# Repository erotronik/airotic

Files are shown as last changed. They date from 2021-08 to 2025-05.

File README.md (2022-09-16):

# Airotic

The next generation of bubbler bottles, with RGB lighting and bluetooth.

## Features

* Borosilicate glass bottle, easy to clean, harder to break
* Customizable RGB lighting which works with or without liquid
* Breath sensor detects each breath and causes the colours to change and fade
* Bluetooth server allows bottles to be customised from your phone
* Proximity sensing lets bottles change colours and modes as they get close to their friends
* Bluetooth client allows other hardware to interact and "do things" based on breaths
* Air input is through vents not a pipe, for aesthetics and safety
* Low cost compared to commercial bottles
* Uses easily sourced parts including bottle, pressure sensor module, Bluetooth Arduino board
* Powered by small USB portable power pack, will run for a day even on the smallest packs
* Can connect to Coyote DG-Labs e-stim box
* Other features and modes to be announced and released
* Open Source software and hardware design

## Background

After discussing how expensive and poorly designed clear bubbler bottles were over a take-away meal, [@toydolly](https://github.com/toydolly) and [@jlatex](https://github.com/jlatex) figured that we could design and make something even better.

Of course it would need little LED lights to make the liquid glow. And bluetooth.  And soon what was a simple "bottle, 3d printed bottle cap, and tube", turned into an Arduino powered, bluetooth, breath detecting, co-operative and interactive project. [Everything is better with Bluetooth](https://youtu.be/0KXoBcQER_0?t=102). 

We really didn't want to make and sell them. So why not build your own? Please do tag and show us if you build one. If you make any improvements to the hardware or software we'd love to see them too, drop an issue or PR here.

## Safety

This bubbler bottle is designed for your own personal use in a situation where you have the ability to disconnect your mask. It is not designed to restrict or block any ability to breathe. The bottle also works just fine without any liquid and will still light up and detect breathing. If you plan to use them at an event please check with an event organiser first.

## Battery Safety

We have designed the bubbler bottle to use an external USB Powerbank. This is deliberate and we did not want to use a LIPO battery. We have personally witnessed several LIPO failures over the years, some while charging, but not always. The last thing you want is your LIPO battery to explode or start venting lithium gasses into your breathing path. 

## Build your own

To make your own bottle you need to buy a few things, 3D print a few things, solder a few things, and use a PC to upload the program.

* [mechanical construction detail and 3D files](mechanical/)
* [electronics construction details](electronics/)
* [programming details](arduino/)
* [user guide](userguide/)

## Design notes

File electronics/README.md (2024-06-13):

# Bubbler Bottle electronics and programming

## Parts list

|Item|UK Seller|USA Seller|
|--|--|--|
| Adafruit Itsy Bitsy NRF52480 Express |[Pimoroni](https://shop.pimoroni.com/products/adafruit-itsybitsy-nrf52840-express-bluetooth-le)| [Adafruit](https://www.adafruit.com/product/4481) |
| BMP280 Barometric pressure sensor |[various ebay sellers](https://www.ebay.co.uk/itm/283518687928)|[various ebay sellers](https://www.ebay.com/itm/133104662930)|
| 2 pairs of micro 3 pin JST 1.25 connectors (or any small 3 pin connectors or just hard wire instead) |[various ebay sellers](https://www.ebay.co.uk/itm/301857866521)|[Adafruit](https://www.adafruit.com/product/4721)|
| Two WS2812b (neopixels) on small round PCB|[various ebay sellers](https://www.ebay.co.uk/itm/203167394144)|[Adafruit](https://www.adafruit.com/product/1612)
| A tiny bit of double sided foam tape (or hotglue)||[Adafruit](https://www.adafruit.com/product/5019)|
| one M2.5 5mm screw|any hardware store or ebay|

Note that it is now possible to use an ESP32 instead of the Adafruit Itsy Bitsy; see this [separate readme](ESP32.md).

## Construction

### Step 1

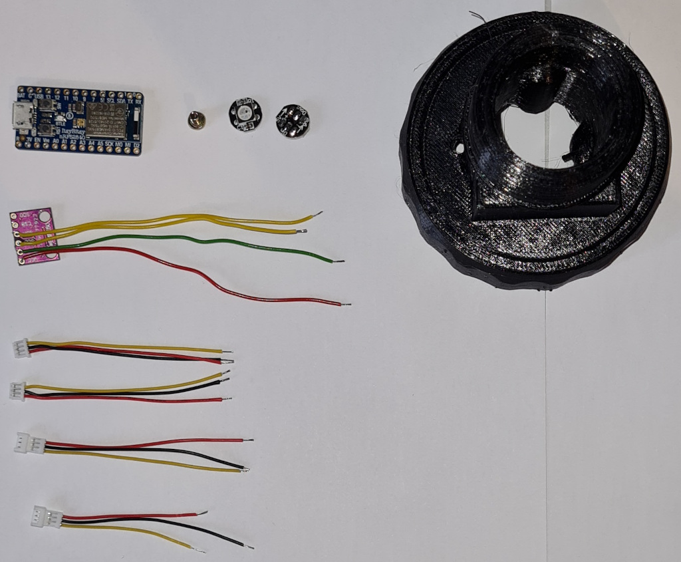
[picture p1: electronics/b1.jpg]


* Shorten 2 male and 1 female JST leads to around 60mm on all 3 connectors, strip, and tin
* Shorten the other female JST lead, black to around 55mm, red and yellow to around 40mm, strip
* Add thin wires to the BMP280 module so the wires come out on the blank side not the component side.  Trim the solder joints so they are not too prominent.  Solder wires about 100mm long to +v and gnd, and wires about 90mm long to SDA and SCL
* Tin the connections on the LED modules to aid assembly.  Do a test fit and make sure they fit in the cap.

### Step 2

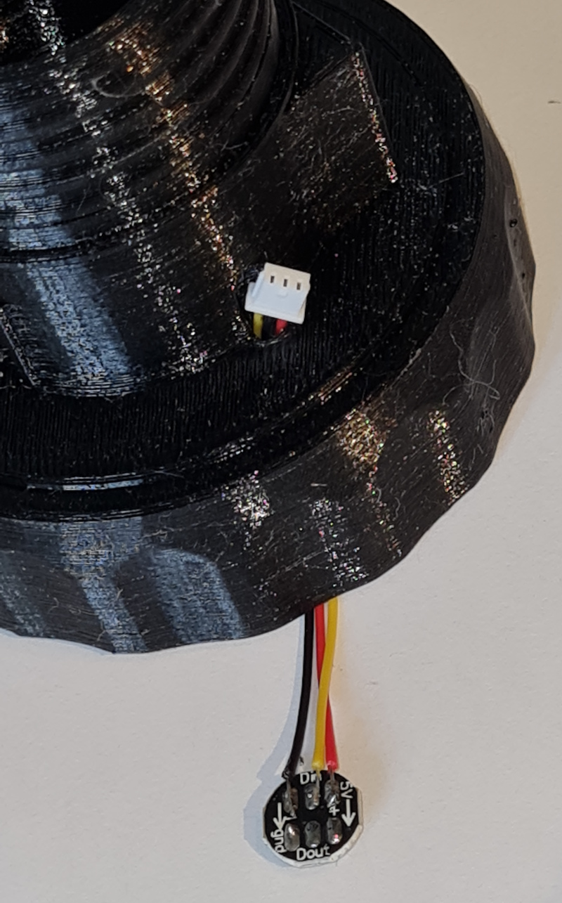
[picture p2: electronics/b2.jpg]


* Feed a male JST through the left hole (left when the flat mounting panel facing you). Solder it to one of the neopixels. Yellow is to DIN, Red is +5V, Black to gnd.  There are no connections to the other 3 pins.

### Step 3

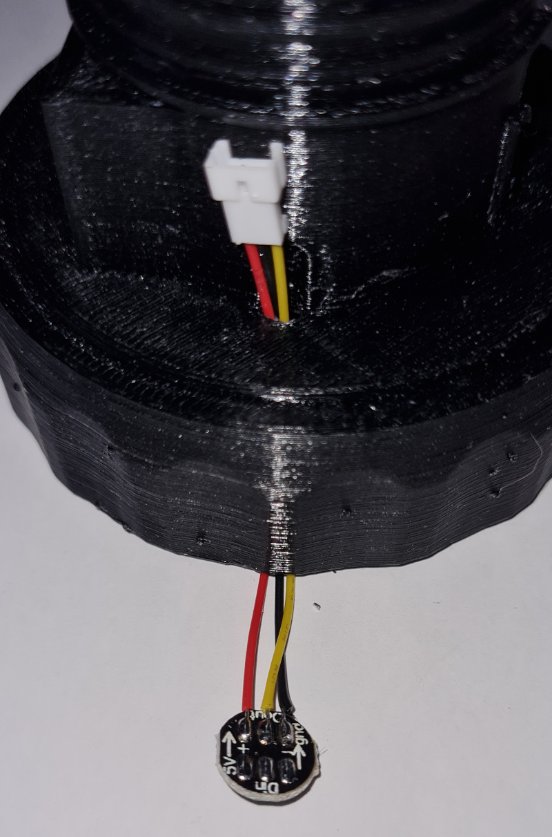
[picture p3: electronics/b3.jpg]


* Feed the 60mm-lead female JST through the right hole. Solder it to the other neopixel. Yellow is DOUT, Red is +5v, black to gnd.

### Step 4

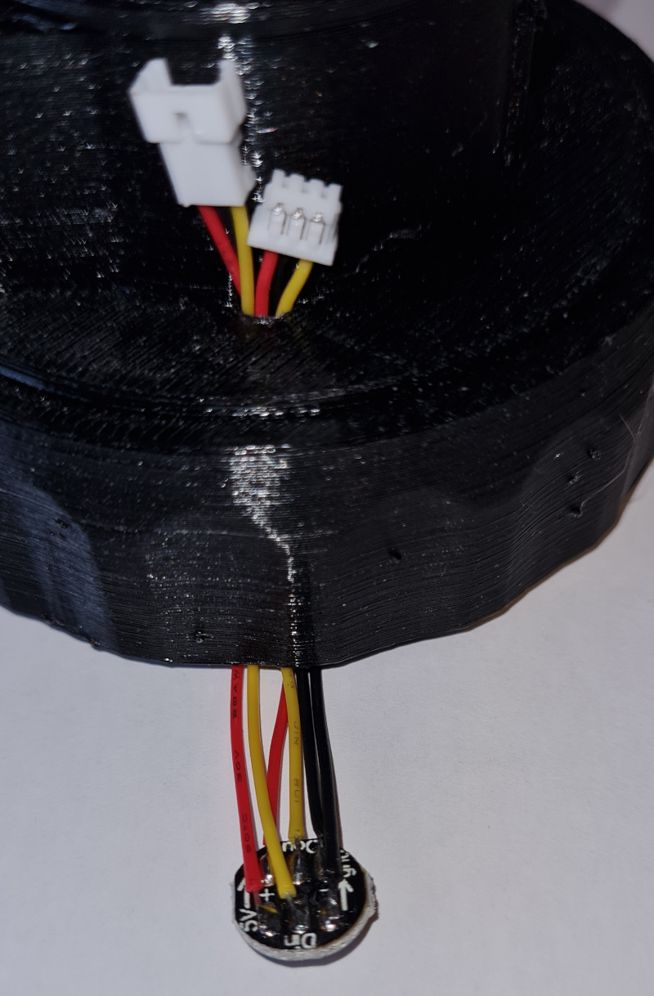
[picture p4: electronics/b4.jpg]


* Feed the remaining male JST lead through the same hole and solder it to the other side of the neopixel. Yellow is DIN, Red is +5v, black to gnd. Solder it so the leads all exit from the same side if possible.  Check your connections carefully make sure DIN and DOUT are not touching.

### Step 5

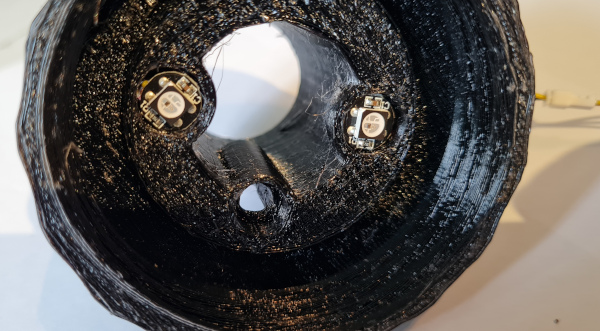
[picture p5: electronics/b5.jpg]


* Carefully push the LEDs back up into the holes for them and bend the wires so they fit as flat as possible. You could install the LED covers at this point to keep them in place.

### Step 6

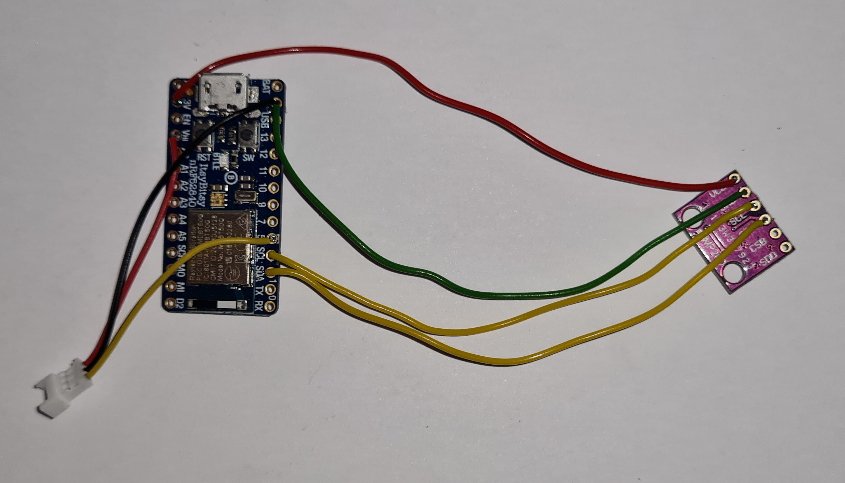
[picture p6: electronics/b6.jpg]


* Solder the remaining JST female and BCM280 board to the Itsy Bitsy.  Start with the GND wire as you need to fit two wires into the same hole.  With thin enough wires this should be fairly easy. Then the JST female red wire goes to the VHI pin, and the JST socket yellow wire goes to the "5!" pin.

* Solder the other wires from the BCM280 board. The red leads goes to 3V, SCL to SCL, and finally SDA to SDA.

### Step 7

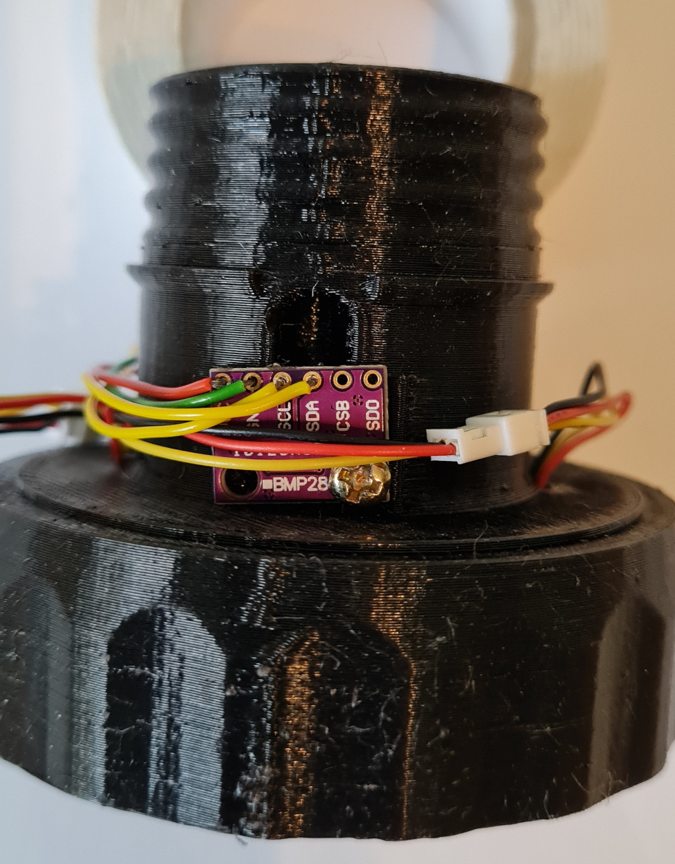
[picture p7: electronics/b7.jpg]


* You can mount the BMP280 board over the air hole using the M2.5 screw. Ensure the component side of the board is against the hole with the leads at the top as shown.  Important: make sure the sensor (the 2mm square silver part) is facing inwards, against the hole.
* Connect all the JST cables and bend/tuck them out of the way.

### Step 8

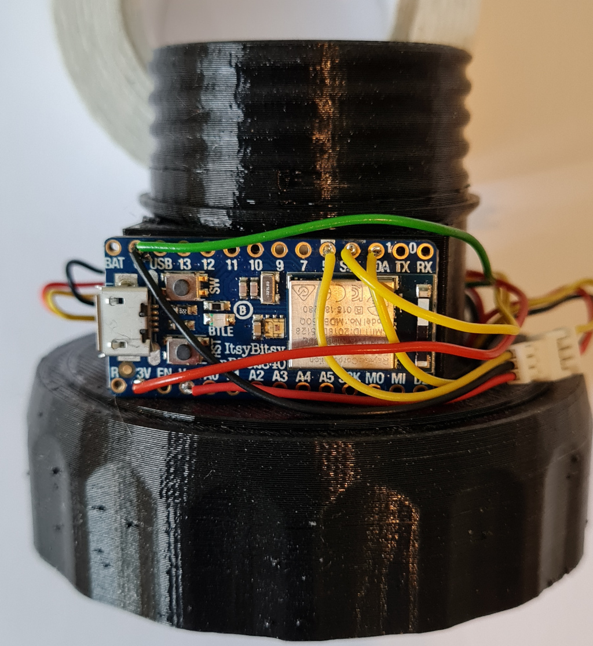
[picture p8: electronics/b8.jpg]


* Secure the Itsy Bitsy board with a bit of double sided foam tape (or hotglue)

That's it, now you just need to program and test.

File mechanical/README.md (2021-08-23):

# Printing and assembling the bottle
## Parts list:
* The STL files for the cap, cover, spigot and LED covers
* A [RYACO 800ml wide mouth bottle](https://www.amazon.co.uk/dp/B088B7RL98/ref=cm_sw_r_tw_dp_RTAABATTSC8DW0E9HZ2Y)
* The seal from the lid of the RYACO bottle
* A short length of 6mm tubing
* Some superglue or similar adhesive

## Construction
### Step 1
* Slice the STL files to suit your 3D printer
* We sliced in Cura at a 0.2mm layer height with supports and 20% infill
### Step 2
* Print your parts 
* We printed in both PLA and PETG for the cap, cover and spigots
* You will need to use transparent filament for the LED caps
### Step 3
* Remove support materials (if you needed supports on the cap, be gentle around the vents)
* Check that the cap fits the bottle properly before proceeding
### Step 4
* On the underside of the cap, superglue the spigot into the hole and leave to set
### Step 5
* Sand, paint or finish to your own taste
* We suggest not altering the area of the cap where the electronics will go to avoid changing the fit
* You can remove the logo on the bottle with a sharp blade by carefully scraping the letters off.
### Step 6
* Remove the seal from the RYACO bottle lid and insert it into the channel on the cap's underside
### Step 7
* Proceed to assembling the electronics before attaching the tube to the spigot for ease of handling.

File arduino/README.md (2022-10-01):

# Bubbler Bottle programming

Note - there is a [separate Readme if you use an ESP32](ESP32.md).

## Programming setup

* Install the arduino tool and board support. [Use this Adafruit guide](https://learn.adafruit.com/adafruit-itsybitsy-nrf52840-express/arduino-support-setup)
* In the arduino tool goto "Tools" "Manage Libraries"
  * Search for "FastLED" and install it
  * Search for "BMP280" and install "Adafruit BMP280 Library"
  * Search for "spiflash" and install "Adafruit_SPIFlash"
  * Search for "NeoPixel" and install "Adafruit NeoPixel"

## Programming first step

* Select the board "ItsyBitsy nRF52840 Express"
* First you need to format the storage we use.  You should only ever need to do this once.  So open the examples "Adafruit SPIFlash" "SdFat_format", write it to the board, open the serial console, and select OK to flash.

## Programming

* Download the Bubbler code and upload it to the board.  On the first run the code will store some defaults and reboot, so it will take a bit longer

* On startup the code will cause both the LEDs to light up white, then shortly after they'll turn pink then fade to red. Blowing hard around the sensor hole will cause them to turn pink and fade back to red again.

Now you can connect to the board via bluetooth and set some defaults if you wish

## Troubleshooting

* On startup both LEDs should turn white briefly. If only one turns white check the connections between the LEDs.

* If the blowing over the sensor doesn't cause anything to happen, look at the serial console in the Arduino
application when starting up. It may be that the sensor isn't being detected. This could be because of a bad
sensor (out of the 6 we bought 1 was faulty) or the connections are bad (check SDA and SCL are the right way
around)

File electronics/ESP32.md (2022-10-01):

# Using an ESP32 for the Bubbler

Instead of the "Adafruit Itsy Bitsy NRF52480 Express", you also can use an ESP32, specifically an "Adafruit QT Py ESP32-C3" ([Adafruit (US)](https://www.adafruit.com/product/5405) / [Pimoroni (UK)](https://shop.pimoroni.com/products/adafruit-qt-py-esp32-c3-wifi-dev-board-with-stemma-qt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)).

Note - it is possible that you can also use other ESP32 boards with the same form factor. However, we only tested this specific board.

To use this board, use the [main construction manual](README.md) with the following changes:

To solder the JST and the BMP280 boards to the ESP32, start with the GND wire, as you need to fit two wires into the same hole. The JST female red wire goes to the "5V" pin, the jst socket yellow wire goes to the "A0" PIN.

Solder the other wires from the BCM280 board. VCC on the BMP280 goes to the "3V" pin, SDA goes to the "SDA" pin and SCL goes to the "SCL" pin.

Since the Adafruit QT Py has a Stemma QT port, you can also solder the BMP280 to a 4-pin JST-ST/Stemma QT cable, and plug that cable into the Qt Py. Suitable cables are available at [Adafruit (US)](https://www.adafruit.com/product/4399) / [Pimorino (UK)](https://shop.pimoroni.com/products/jst-sh-cable-qwiic-stemma-qt-compatible?variant=31910609813587). You will probably have to get a cable with two JST-SH ports, and cut it apart.

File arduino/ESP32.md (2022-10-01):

# ESP32 Bubbler Bottle programming

This is the programming guide if you choose to use an ESP32 instead of the (recommended) ItsyBitsy nRF52840 Express. For the ItsyBitsy, please [see the main readme](README.md).

## Programming setup

* Install the [Arduino IDE](https://www.arduino.cc/en/software) and [the Espressif ESP32 boards](https://espressif-docs.readthedocs-hosted.com/projects/arduino-esp32/en/latest/installing.html)
* In the Arduino IDE, go to "Tools"->"Manage Libraries"
* Search for, and install the following libraries:
	- FastLED
	- Adafruit NeoPixel
	- NimBLE-Arduino
	- Adafruit BMP280 Library

## Programming
* Select the board "Adafruit QT Py ESP32-C3"
* Download the Bubbler code and upload it to the board. On the first run the code will store some defaults and reboot, so it will take a bit longer.
* On startup the code will cause both the LEDs to light up white, then shortly after they'll turn pink then fade to red. Blowing hard around the sensor hole will cause them to turn pink and fade back to red again.

Now you can connect to the board via bluetooth and set some defaults if you wish

## Wifi Support

You can enable wifi support by changing the `ENABLE_BLE` and `ENABLE_WIFI` defined inside `bubbler.ino`.

Wifi support is quite rough at the moment; if you want to use it you should be familiar with Arduino programming and look at wifi.ino.

To use Wifi, you need to install the following additional libraries using the library manager:
* AsyncMQTT_Generic

You also have to manually install the following library that is not available via the library manager:
* https://github.com/me-no-dev/AsyncTCP

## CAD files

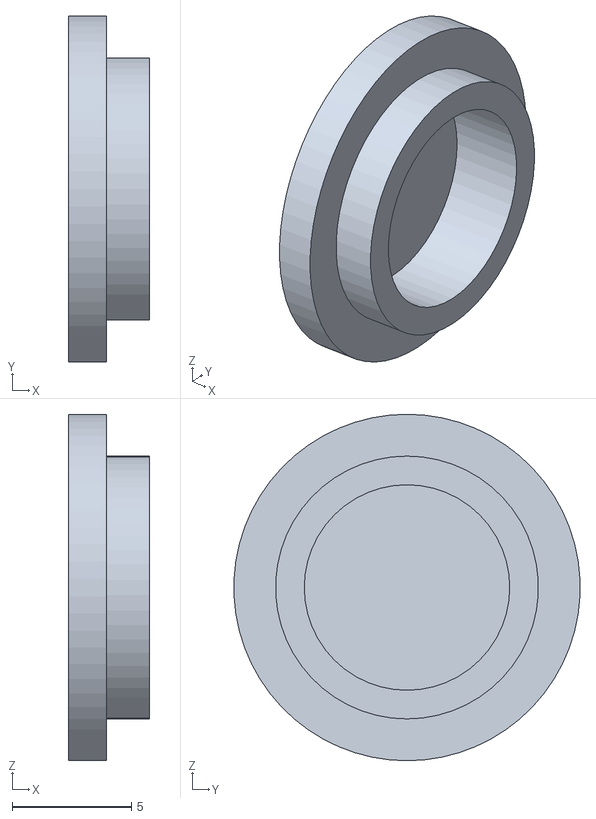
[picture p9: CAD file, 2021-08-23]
mechanical/2501-004 A.STL
3.40 x 14.5 x 14.5

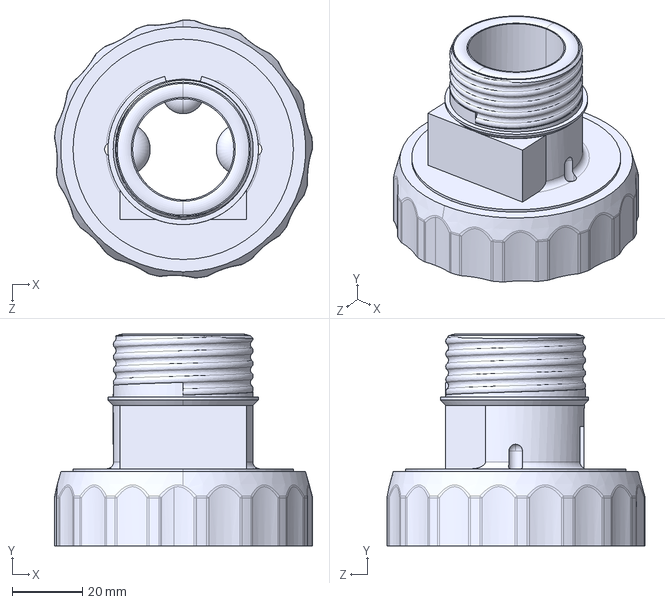
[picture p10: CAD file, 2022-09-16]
mechanical/STEP Files/2501-001.STEP
73.5 x 60.4 x 73.5 mm

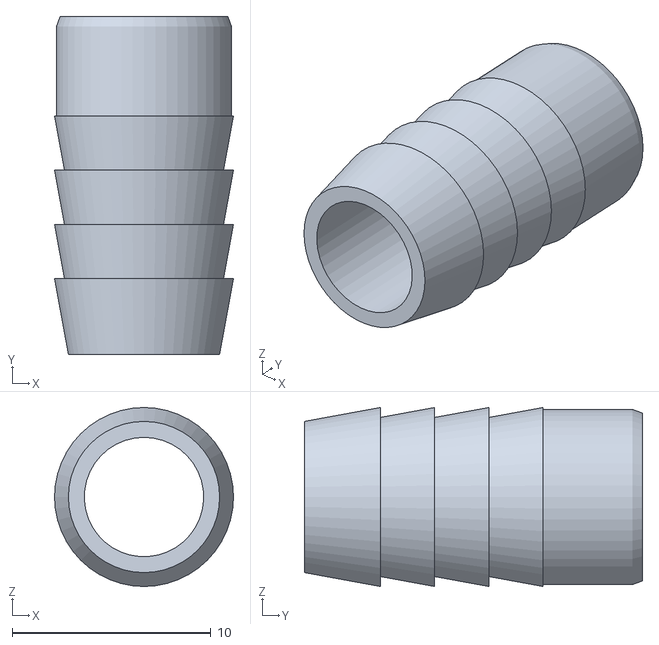
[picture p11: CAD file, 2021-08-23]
mechanical/2501-003 A.STL
9.00 x 17.0 x 9.00

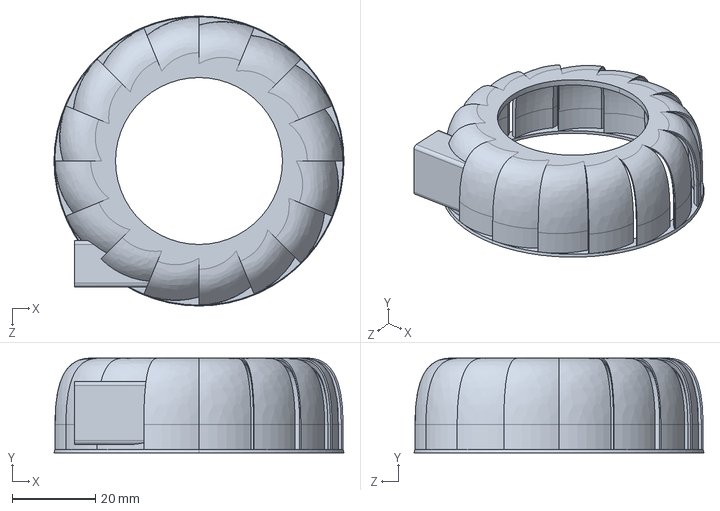
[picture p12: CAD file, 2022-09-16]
mechanical/STEP Files/2501-002.STEP
69.8 x 22.8 x 69.8 mm

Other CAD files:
mechanical/2501-001 A.STL
mechanical/2501-002 A.STL

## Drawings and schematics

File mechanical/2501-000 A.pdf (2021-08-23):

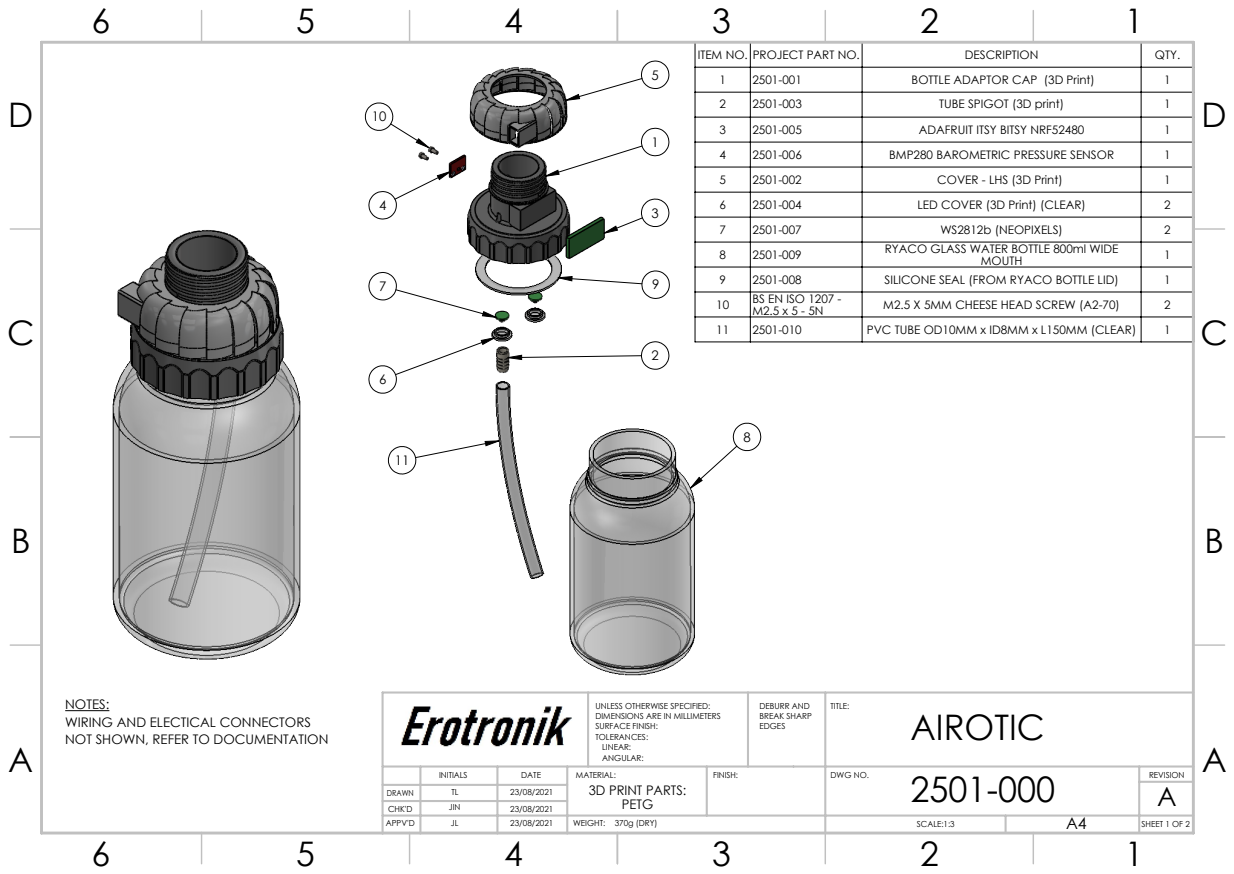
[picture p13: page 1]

ITEM NO. | PROJECT PART NO. | DESCRIPTION | QTY.
1 | 2501-001 | BOTTLE ADAPTOR CAP (3D Print) | 1
2 | 2501-003 | TUBE SPIGOT (3D print) | 1
3 | 2501-005 | ADAFRUIT ITSY BITSY NRF52480 | 1
4 | 2501-006 | BMP280 BAROMETRIC PRESSURE SENSOR | 1
5 | 2501-002 | COVER - LHS (3D Print) | 1
6 | 2501-004 | LED COVER (3D Print) (CLEAR) | 2
7 | 2501-007 | WS2812b (NEOPIXELS) | 2
8 | 2501-009 | RYACO GLASS WATER BOTTLE 800ml WIDE MOUTH | 1

9 | 2501-008 | SILICONE SEAL (FROM RYACO BOTTLE LID) | 1
10 | BS EN ISO 1207 -M2.5 x 5 - 5N | M2.5 X 5MM CHEESE HEAD SCREW (A2-70) | 2

11 | 2501-010 | PVC TUBE OD10MM x ID8MM x L150MM (CLEAR) | 1

NOTES:
WIRING AND ELECTICAL CONNECTORS
NOT SHOWN, REFER TO DOCUMENTATION

UNLESS OTHERWISE SPECIFIED: DIMENSIONS ARE IN MILLIMETERS SURFACE FINISH: TOLERANCES: LINEAR: ANGULAR: | DEBURR AND BREAK SHARP EDGES | TITLE: AIROTIC

JIN INITIALS | DATE | MATERIAL: 3D PRINT PARTS: PETG | FINISH: | 2501-000 DWG NO. | REVISION A 23/08/2021

DRAWN | TL
CHK'D | | 23/08/2021
APPV'D | JL | 23/08/2021 | WEIGHT: 370g (DRY) | SCALE:1:3 | A4 | SHEET 1 OF 2

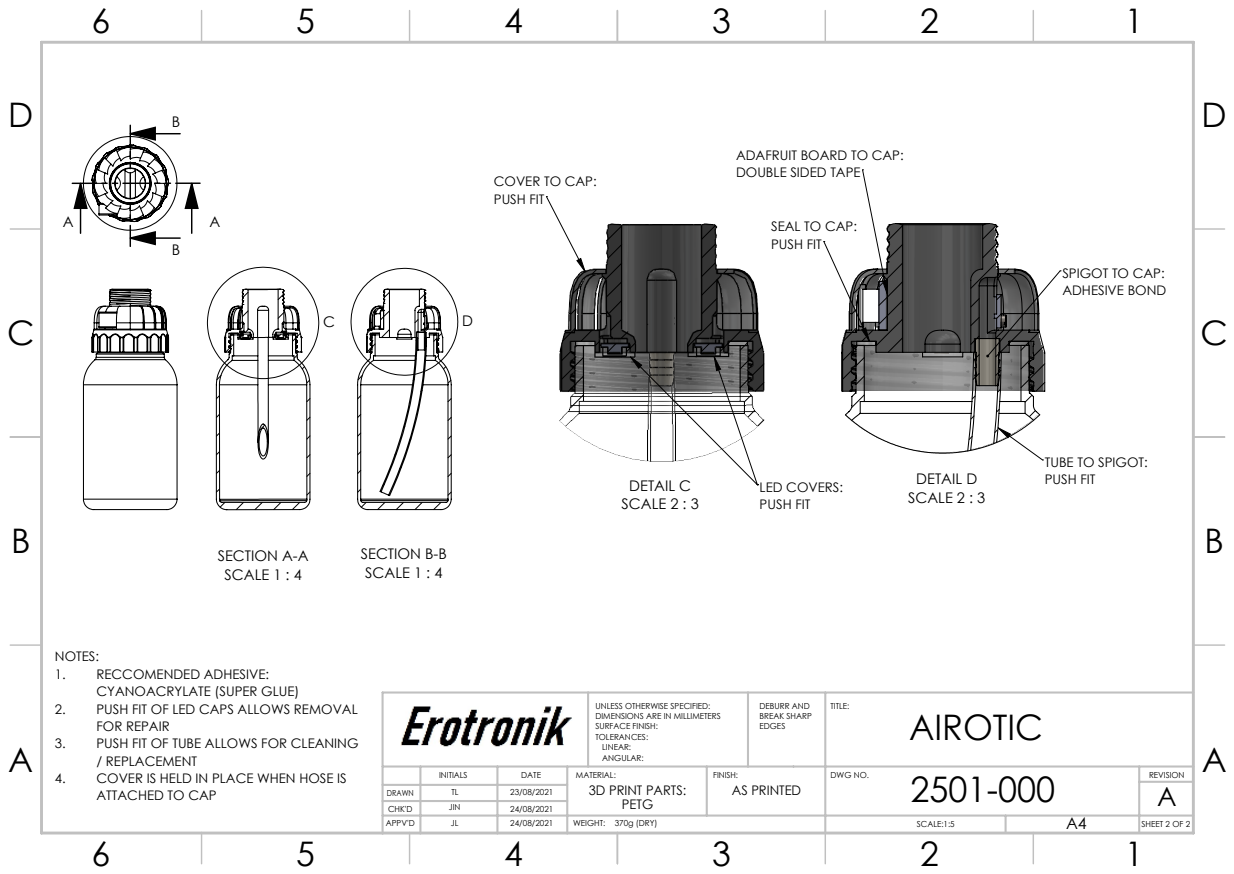
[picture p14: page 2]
SECTION A-A SCALE 1 : 4; SECTION B-B SCALE 1 : 4; DETAIL C SCALE 2 : 3; LED COVERS: PUSH FIT; DETAIL D SCALE 2 : 3; / REPLACEMENT; ATTACHED TO CAP; DRAWN

ADAFRUIT BOARD TO CAP:
DOUBLE SIDED TAPE

COVER TO CAP:
PUSH FIT

SEAL TO CAP:

SPIGOT TO CAP:
ADHESIVE BOND

TUBE TO SPIGOT:

NOTES:
1. RECCOMENDED ADHESIVE:
CYANOACRYLATE (SUPER GLUE)
2. PUSH FIT OF LED CAPS ALLOWS REMOVAL
FOR REPAIR
3. PUSH FIT OF TUBE ALLOWS FOR CLEANING
4. COVER IS HELD IN PLACE WHEN HOSE IS

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

JIN INITIALS | DATE | MATERIAL: 3D PRINT PARTS: PETG | FINISH: AS PRINTED | 2501-000 DWG NO. | REVISION A 23/08/2021

CHK'D | | 24/08/2021
APPV'D | JL | 24/08/2021 | WEIGHT: 370g (DRY) | SCALE:1:5 | A4 | SHEET 2 OF 2

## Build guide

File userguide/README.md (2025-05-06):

# User Guide for connecting to DG-Labs Coyote box

The bottle will look for DG-Labs Coyote bluetooth powerboxes. If it
finds one it will connect to it and send 5 'breath' waves to both A
and B channels at level '150' (defined in coyote.h, usually 2000
max). Then every breath sends a 'breath' wave to channels A and B. You
can alter the level up and down using the rocker switches on the box,
these are forgotten when you disconnect.  Holding a rocker switch will
reset the channel to zero and you'll need to disconnect or restart the
bottle to get back to the default.

Note that it will only connect to one box at a time. If you are in an
environment like a club where there might be other devices please be
careful as it will connect to any boxes that are currently turned on and
not being used by some other app.

# User Guide for connecting via bluetooth

You can connect to the device using any bluetooth serial (UART) application, but the easiest is the phone app ["Bluefruit Connect"](https://learn.adafruit.com/bluefruit-le-connect) from Adafruit.

## Setting the bottle number

Pick a bottle number between 1 and 19. Use an odd number (even numbers are reseved for bottles that act differently). To set the bottle ID to 5:

Select UART mode and type <pre>!S05</pre>

The bottle will respond "ok" and then reboot.  The bottle number is used when you have more than one bottle in use for proximity and also for the bluetooth ID.

## Display current bottle number

In UART mode type <pre>!H</pre>

## Set the rest colour

* In the app select "Controller" "Control Pad" and hit button 1.

* Go back and select "Colour Picker" and select the colour you want to use.

## Set the blow colour

* In the app select "Controller" "Control Pad" and hit button 2.

* Go back and select "Colour Picker" and select the colour you want to use.

## Go back to default of all colours

In UART mode type <pre>!B3</pre> or in the app select "Controller" "Control Pad" and hit button 3

## Reboot device

In UART mode type <pre>!B4</pre> or in the app select "Controller" "Control Pad" and hit button 4

## Debug mode: breath sensor

In UART mode type <pre>!D1</pre>.  You will start to receive the breath sensor data.  Go back and select "Plotter" to get a live graph of readings from the breath sensor. One line is the current value, the other the moving average. Each breath should cause a significant negative peak.

In the current code this mode is disabled, you'll need to uncomment line 184/185 in bubbler.ino

## Debug mode: proximity sensor

In UART mode type <pre>!D2</pre>.  You will start to receive the proximity sensor data of any other bottles in range.  Go back and select "Plotter" to get a live graph of proximity (RSSI).

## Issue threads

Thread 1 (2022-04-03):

2nd LED behaving strange

kevkov202, 2022-04-03:
Hey,

first of all: Great Project! I love the idea and immediately had to build it when I saw it the first time.

Putting it togeter etc. went really wellt. But I can't get the LEDs to work properly. The 1st one in the chain works as described. But the 2nd one is green when powering up and turns yellow afterwards. When I blow at the sensor the 1st one goes pink as it should but the 2nd one goes green again.

I have resoldered it 2 times now and even switched both neopixels (with each other and also new ones) to make sure there are no hardware issues. Its always the 2nd one in the chain thats not working. Also measured if the connections are right and that Din/Dout are not touching or the solder pads are bridged.

I am totally out of ideas now, do you maybe have another hint what could be wrong?

latexjess, 2022-04-07:
I built this project a few weeks ago without any issues - I didn't deviate from the BOM, followed all guides, and used the latest version of each recommended library.

Did you source your LEDs from Adafruit?
Did you test all connections? (perhaps LED grounding)

Can you confirm your library versions?

Here's what I'm using:
- FastLED 3.5.0
- Adafruit BMP280 Library 2.6.2
- Adafruit SPIFlash 3.9.0

Hope this helps!

jlatex, 2022-04-17:
Oh how strange, if you swap pixels and get the same effect then that points to a possible code issue, but the code is really simple for driving the LEDs. We're using FastLED 3.4.0 library. Are you using the suggested ItsyBitsy and the level shifted pin (5)?  Have you connnected the power for the NeoPixels to 5v and not 3.3v?

jlatex, 2022-04-18:
If your voltage is correct there is another thing you could do.... since both LEDs are always driven to the exact same colour every time it doesn't really matter that you can address both individually. So you could just connect the DIN of the 2nd LED to the DIN of the 1st LED (instead of the DOUT). Bit of a hack, but it'd probably solve the issue!

Closed 2022-10-01.

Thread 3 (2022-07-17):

Question about Tube spigot

Zyrin36, 2022-07-17:
Was wondering is the spigot supposed to fit inside the Bottle adapter caps third hole? With what I got printed they only seam to connect on the outside and it dosnt slide into it.

Not sure if its the material or the way it was printed. Think I can still super glue it on top of the hole if it comes to that.

ToyDolly, 2022-08-07:
Sorry for the late reply. It should slot in, so check the print settings and make sure all the support was removed. Failing that, a bit of sanding should sort it out

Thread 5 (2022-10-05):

Mechanical fix to protect the sensor

jlatex, 2022-10-05:
The BMP280 sensor must be protected against liquid ingress, but it's possible for the water in the bottle under some circumstances to reach the sensor. We should test how the responsiveness is affected using kapton tape/ePTFE  over the sensor (or make changes to the air path in the 3d print)

(Verified that water in a BMP280 sensor caused it to fail permanently)

naaitsab, 2022-10-17:
Passing the airflow trough a "gooseneck" pipe would fix the ingress issue. One could make a gooseneck pipe that attached to the clear 'bubbler' hose so the main design, due to size restrictions can be left unchanged. It will make the pipe a bit more visible but will also make the choice user based and will result in them printing pipe A or B.

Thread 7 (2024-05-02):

Debugging mode 1 not working

Leyre-375, 2024-05-02:
When sending the !D1 through the UART, no changes are made, and the plotter doesn't show data.

I've traced the issue to the line supposed to send this information being commented: line 184 in file bubbler.ino

Either the documentation should be updated or the line uncommented.

Love this device. Great job!

Kind regards

Closed 2025-05-06.

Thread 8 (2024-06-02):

request: possibility to adjust sensitivity of BMP280

moarkaboom, 2024-06-02:
First off: Awesome project, thank you so much for providing this to us!!

I was noticing that the sensor would not always trigger with every breath, and that I would have to really breath in fast and deep to trigger the BMP. Would it be possible to adjust the sensitivity? Either by debugging (UART) command, or directly in the code?

moarkaboom, 2024-06-02:
Nevermind, if you mount the BMP facing the correct side (sensor into the hole), the bubbler triggers just fine.

jlatex, 2024-06-13:
glad you got it sorted!

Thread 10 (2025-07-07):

Unable to Connect to Coyote V3

Cobrafrogman, 2025-07-07:
I started to create my own aitotic, however unable to get it to find my coyote. I assume it is because it is a v3. I am using a ESP32 xiao-esp-c3. I flashed another esp -wroom-32. I had no luck connecting. When both where powered on they saw each other.

jlatex, 2025-07-13:
Hiya; the code currently was only written for the v2 coyote, but we've just updated our library to support v3 so supporting it here should be possible soon.

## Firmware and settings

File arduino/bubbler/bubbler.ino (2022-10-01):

// Bluetooth Bubbler Bottle
//
// Bottle lights a (configurable) "at rest" colour. On every detected
// breath it changes to a (configurable) "breath" colour then fades
// back to "at rest".
//
// Bottles detect other bottles in range and when close enough they will
// sync their lights to match colours. They do this by looking at the
// bluetooth advertising data and do not connect to each other.
//
// You can connect to the Bottle by bluetooth to configure it, you also
// get a notification of breath and release so you can "make other things
// happen"
//
// Hardware:
//
// When using ItsyBitsy nRF52840 Express
//
// BMP280 on SDL/SCA/3v/0v, two WS2812b (neopixels) chained on pin 5/+V/0v
//
// When using QT Py ESP32-C3
//
// BMP280 on SDL/SCA/3v/0x, two WS2912b (neopixels) chained on pin A0/5V/GND
//
// Use the Adafruit controller app "Controller"
// Push Control pad 1 - then use color picker for "at rest" colour
// Push Control pad 2 - then use color picker for "bubble" colour
// Push Control pad 3 - to reset to more sensible defaults
// Push Control pad 4 - restart device so we advertise correct colours and name
// Use UART mode and type "!S1" to set device to ID 1 (1-9 allowed)
//
// This version will also look for DG-Labs Coyote bluetooth powerboxes. If it
// finds one it will connect to it and send 5 'breath' waves to both A and B
// channels at level '150' (defined in coyote.h, usually 2000 max). Then every breath
// sends a 'breath' wave to channels A and B. You can alter the level up and down
// using the rocker switches on the box, these are forgotten when you disconnect.  Holding
// a rocker switch will reset the channel to zero and you'll need to disconnect or restart
// the bottle to get back to the default.

// rssi average below which we merge the LEDS of seen bottles
// not configurable as kind of needs to be the same on each bottle to work
#define DISTANCE_TO_SYNC_LEDS 64

#include <FastLED.h>
#include <Adafruit_NeoPixel.h>

#define ENABLE_BLE /* uncomment to enable BLE communications */
//#define ENABLE_WIFI /* uncomment to enable WIFI communications, only ESP32 */

#define PIXEL_TYPE NEO_GRB + NEO_KHZ800 /* The Pixel type that you have, defined as per Adafruit neopixel library. You might have to change, e.g. the color order */

#define MAX_BOTTLES 16 /* Maximum bottles supported for BLE communication */
#define NUM_LEDS 2 /* Number of LEDS - this is two, unless you change the hardware */
// #define LED_DATA_PIN 5 /* the data pin on which the LED is. This is automatically set below - only change if you need it to be different */

#ifdef ESP32
#include "NimBLEDevice.h"
#ifdef ENABLE_WIFI
#include <WiFi.h>
#include <AsyncMqtt_Generic.h>
#endif /* ENABLE_WIFI */ 
#endif /* ESP32 */

#ifndef ESP32
#include <bluefruit.h>
#endif

typedef struct {
  CHSV colorTarget;
  CHSV colorStart;
  int rssi_av;
  long rssi_last;
  short state; // 0 away, 1 close
  boolean changed_state;
} bottle_t;
bottle_t seen_bottles[MAX_BOTTLES];

#ifndef LED_DATA_PIN
#ifndef ESP32
// ItsyBitsy has level-shift on pin 5
#define LED_DATA_PIN 5
#else
// On QT Py, use A0
#define LED_DATA_PIN 4
#endif
#endif

Adafruit_NeoPixel px = Adafruit_NeoPixel(NUM_LEDS, LED_DATA_PIN, PIXEL_TYPE);

CHSV colorTargetDefault = CHSV(160, 255, 255); // blue is 160, green is 96
CHSV colorStartDefault = CHSV(224, 255, 255); // purple is 192, red is 0
CHSV colorTarget = colorTargetDefault;
CHSV colorMyTarget = colorTargetDefault;
CHSV colorStart = colorStartDefault;
CHSV colorWas;
CHSV colorMyStart = colorStart;
CHSV colorCurrent = colorTarget;
uint8_t fadespeed = 64;
short bottle_number = 1;
int avg;
short blow_state = 0;
int fade = 0;
long xm = millis();
long y = 0;
int nearest_bottle_percent = 100;

// set this via bluetooth, 1==bluetooth send the bmp sensor read and average
short debug_mode = 0;

// this belongs into comms.ino. But it has to be in a separate file because - Arduino.
enum scan_callback_result {None, Coyote, Bottle};

void leds_setup() {
  // "Boot" mode
  px.begin();
  px.setPixelColor(0, 255, 255, 255);
  px.setPixelColor(1, 255, 255, 255);
  px.show();

  //FastLED.addLeds<NEOPIXEL, LED_DATA_PIN>(leds, NUM_LEDS);
  //FastLED.setBrightness(255);
  //leds[0] = CRGB::White;
  //leds[1] = CRGB::White;
  //FastLED.show();
}

void leds_startingstate() {
  colorCurrent = colorMyTarget;
  //fill_solid( leds, NUM_LEDS, colorCurrent );
  //FastLED.show();
  CRGB rgbcolor = colorCurrent;
  px.fill( px.Color(rgbcolor.r, rgbcolor.g, rgbcolor. b), 0, NUM_LEDS );
  px.show();
}

void leds_do_fade() {
  // If we're not 'at rest' colour then fade towards it
  if ( colorCurrent.h != colorTarget.h ) {
    fade = min(fade + fadespeed, 255);
    colorCurrent = blend(colorWas, colorTarget, fade, SHORTEST_HUES);
    CRGB rgbcolor = colorCurrent;
    //fill_solid( leds, NUM_LEDS, colorCurrent );
    //FastLED.show();
    px.fill( px.Color(rgbcolor.r, rgbcolor.g, rgbcolor.b), 0, NUM_LEDS);
    px.show();
  }
}

void check_breath() {
  //
  // Read the sensor and get an average, detect the start of a blow/suck and the end of a blow/suck
  // the detection of the end isn't accurate, but we do a fade so you won't notice.
  //
  // moving average was by trial and error, let's do 60% old, 40% new
  // blow threshold was by trial and error, 50 seemed to work quite well
  // 20210729 move avg to end, 80% old 20% new and threshosd 15
  //
  #define avthres 15
  int pread = airsensor_read();
  if (blow_state == 0 && pread < (avg - avthres)) {
    blow_state = 1;
    fade = 0;
    // fade, but slow while the breath is happening
#ifdef ENABLE_BLE
    comms_send_breath(true);
#endif
#ifdef ENABLE_WIFI
    wifi_send_breath(true);
#endif
    fadespeed = 4;
    colorCurrent = colorStart;
    colorWas = colorStart;
  } else if (blow_state == 1 && pread > avg) {
    blow_state = 0;
#ifdef ENABLE_BLE
    comms_send_breath(false);
#endif
#ifdef ENABLE_WIFI
    wifi_send_breath(false);
#endif
    // fade back faster now the breath has 'stopped'
    fadespeed = 16;
  }
  //if (debug_mode & 1) comms_uart_send_graph(pread, avg);
  //Serial.printf("%d,%d,%d\n",pread,avg,avg-avthres);
  avg = (avg * 8 + pread * 2) / 10;
}

void debug_checkcodespeed() {
  //
  // just for debugging: if something in the code is eating all the time we might need to be more careful with the delays
  //
  y++;
  if (millis() > xm + 1000) {
    xm = millis();
    if (y < 9) Serial.printf("SLOWTICK %d\n", y);
    y = 0;
  }
  if (millis() / 100 % 30 == 0) {
    for (short i = 0; i < MAX_BOTTLES; i++) {
      if (seen_bottles[i].rssi_av < 128) {
        Serial.printf("Bottle %d : %d\n", i, seen_bottles[i].rssi_av);
      }
    }
  }
}

void look_for_close_bottles() {
#ifdef ENABLE_BLE
  //
  // Any other Bottles close?  "Merge" colours if 2, Fixed colour if 3
  //
  short n = 0;
  int closestd = 128;
  if (debug_mode & 2) comms_uart_send_bottles();

  for (short i = 0; i < MAX_BOTTLES; i++) {
    if (seen_bottles[i].state != 0) {
      if (seen_bottles[i].rssi_av < closestd) closestd = seen_bottles[i].rssi_av;
    }
  }
  nearest_bottle_percent = min(0,closestd-28);

  for (short i = 0; i < MAX_BOTTLES; i++) {
    if (seen_bottles[i].changed_state) {
      n = 1;
      Serial.printf("State Change Bottle %d : %d\n", i, seen_bottles[i].rssi_av);      
      seen_bottles[i].changed_state = false;
    }
  }
  if (n == 0) return;

  // n = 1 if any bottles have changed state, figure out how many are close

  n = 0;
  for (short i = 0; i < MAX_BOTTLES; i++) {
    if (seen_bottles[i].state != 0) {
      n++;
      colorTarget = blend(colorMyTarget, seen_bottles[i].colorTarget, 128, SHORTEST_HUES);
      colorStart = blend(colorMyStart, seen_bottles[i].colorStart, 128, LONGEST_HUES);          
    }
  }
  Serial.printf("Bottles close: %d\n",n);

  if (n == 0) {
    colorTarget = colorMyTarget;
    colorStart = colorMyStart;
  } else if (n > 1) {
      //
      // 2 or more bottles? blend is no use so let's just use a fixed default
      //
      colorTarget = CHSV(255, 255, 255);
      colorStart = CHSV(42, 255, 255);
  } // otherwise n==1 use the one we found above.
#endif
}

void bottle_setup() {
  // MAX_BOTTLES green bottles, sitting on a wall...
  for (short i = 0; i < MAX_BOTTLES; i++) {
    seen_bottles[i].rssi_av = 128;
    seen_bottles[i].changed_state = false;
  }
}

// Main Entry Points are Below

void setup() {
  Serial.begin(115200);
  bottle_setup();
  leds_setup();
  delay(1500);
  airsensor_setup();
  avg = airsensor_read();
  storage_setup();
#ifdef ESP32
#ifdef ENABLE_WIFI
  wifi_setup();
#endif
#endif
  leds_startingstate();
#ifdef ENABLE_BLE
  comms_init(bottle_number);
#endif
  Serial.printf("I am bottle number %d\n", bottle_number);
  xTaskCreate(TaskMain, "Main", 10000, nullptr, 1, nullptr);
#if defined(ENABLE_BLE) && defined(ESP32)
  xTaskCreate(TaskScan, "Scan", 10000, nullptr, 2, nullptr);
#endif
}

void main_loop() {
#ifdef ENABLE_BLE
  comms_uart_colorpicker();
#endif
  debug_checkcodespeed();
  check_breath();
#ifdef ENABLE_BLE
  comms_check_distance(DISTANCE_TO_SYNC_LEDS);
  look_for_close_bottles();
#endif /* ENABLE_BLE */
  leds_do_fade();
  delay(100);
}

// Leave empty - we are using FreeRTOS tasks instead of the Arduino main loop
void loop() {
}

void TaskMain(void *pvParameters) {
  vTaskDelay(200);
  while (true)
    main_loop();
}

// On the ESP32, we scan in a separate task - scanning is a blocking
// operation. All the communication with the Coyote also happens
// in this task.
#if defined(ENABLE_BLE) && defined(ESP32)
void TaskScan(void *pvParameters) {
  while (true) {
    scan_loop();
  }
}
#endif

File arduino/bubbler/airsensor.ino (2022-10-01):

#include <Wire.h>
#include <Adafruit_BMP280.h>

Adafruit_BMP280 bmp;

// Track if we do have an airsensor. If no, just return a 0 for read, but otherwise work.
// This lets us, e.e., debug BLE with just a board, even if it does not feature a sensor.
bool have_airsensor = true;

void airsensor_setup() {
  if (!bmp.begin(0x76, BMP280_CHIPID)) {
    Serial.println("Missing BMP280");
    have_airsensor = false;
    return;
  }

  bmp.setSampling(Adafruit_BMP280::MODE_NORMAL,
                  Adafruit_BMP280::SAMPLING_NONE, /* No temperature */
                  Adafruit_BMP280::SAMPLING_X1, /* Pressure, no oversampling */
                  Adafruit_BMP280::FILTER_OFF, /* No Filtering */
                  Adafruit_BMP280::STANDBY_MS_63); /* Standby time */
}

int airsensor_read() {
  if ( ! have_airsensor )
    return 0;

  return bmp.readPressure();
}

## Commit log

2021-08-23 Create amazonbottle.png
    The 3D print files assume that you are using a RYACO 800ml wide mouthed bottle which we sourced on Amazon. You will also need the rubber seal from inside the cap.
2021-08-23 Separate soldering into another file
2021-08-23 Added STL files and diagram
    [2501-001 A.STL, 2501-002 A.STL, 2501-003 A.STL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]
2021-08-24 Add Arduino code
2021-11-10 Fix a bug found at an event. When you select a colour with the colour wheel then display the colour converted to HSV because that's what you'll get in the end not the RGB approximation
    [comms.ino]
2022-08-13 Update to consolidate the serial and bluetooth messages based on code from heavyrubberslave in PR#
    Resolves: https://github.com/erotronik/airotic/pull/2
    [bubbler.ino, comms.ino]
2022-08-13 Add LIPO warning
2022-08-14 ESP32 compileability and Led library switch
    This is very much WIP. With these changes, the code compiles on the
    Adafruit QT Py ESP32-C3 - without BLE or storage functionalities.
    This also switches the library that drives the LEDS to the Adafruit
    NeoPixel library - to support RGBW pixels that are ill-supported by
    FastLED. All color calculations are still done by fastled.
2022-08-16 Basic WiFi + MQTT support
    Pushed breath information into MQTT; optionally can send commands to
    switch color to wled (via MQTT).
    More of a POC - this needs more work.
2022-08-20 Implement ESP32 uart mode
    This change implements the same uart commands that are supported when
    using the nRF52840; advertising is performed under the same name.
    This does not (yet) implement advertising and recognizing other
    bubblers. It also does not support coyotes.
    This also conflicts with wifi.
2022-08-26 Start of code for BLE communication with DG-Lab box.
    A bit problematic for several reasons.
    [bubbler.ino, comms.ino, coyote.ino]
2022-08-26 Switch to NimBLE
2022-08-26 Intruduce a couple of defines to enable/disable features.
    New: compiles on both platforms.
2022-09-02 Switch everything to NimBLE
2022-09-02 BLE working on ESP32-C3 and Itsy Bitsy
2022-09-16 Added STEP files
    More detailed 3D files for those that want to make adaptations
    [2501-001.STEP, 2501-002.STEP]
